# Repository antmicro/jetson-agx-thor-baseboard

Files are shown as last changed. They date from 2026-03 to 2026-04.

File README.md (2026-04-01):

# Antmicro baseboard for Jetson AGX Thor

Copyright (c) 2025-2026 [Antmicro](https://www.antmicro.com)

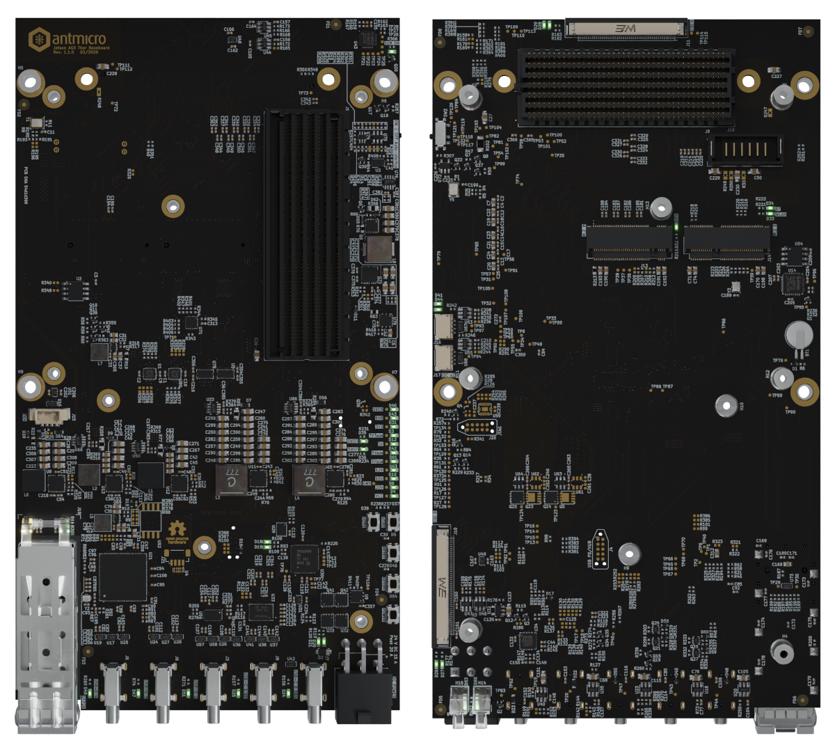
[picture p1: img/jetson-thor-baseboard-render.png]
Jetson Thor Baseboard


## Overview

This repository contains open hardware design files for Antmicro's baseboard for the [NVIDIA Jetson AGX Thor (T5000)](https://www.nvidia.com/en-us/autonomous-machines/embedded-systems/jetson-thor/) System on Module.
The baseboard break-routes common IO-interfaces for standard desktop usage and potential customizations for use in embedded products, [offered as a service](https://offering.antmicro.com/#/hw-process#overview).
The baseboard also features an FMC-style expansion connector, and can be combined with custom-designed accessories in order to accelerate the development of new Thor-based products.
The PCB design files were prepared in KiCad 9.x.

## Key features

* 2 x 50-pin FFC connectors exposing 4 x 4-lane CSI ports from the SoM with independent I2C configuration buses per each CSI port
* SFP port exposing Jetson Thor XFI interface for fiber or copper modules
* M.2 (key-M) for NVMe storage (suggested usage)
* M.2 (key-E) for wireless adapters
* FMC+ expansion connector with PCIe x2, PCIe x1, DisplayPort, CAN, UART, SPI, I2S
* On-board USB 3.2 hub with two downstream-facing ports exposed on USB-C connectors
* Recovery USB-C port for writing Board Support Package (BSP) images to the SoM
* Generic USB-C port which supports video ALT mode and 100 W USB PD sink/source
* Debug USB-C port with debug console and 100 W USB PD sink/source support
* General purpose on-board 8KB EEPROM
* On-board Infineon/SLB9673AU20FW2610XTMA1 TPM
* Two user buttons
* Two user LEDs
* FAN connector
* 100 x 180 mm (3.93 x 7.09 inch) PCB outline

The baseboard has two 50-pin FFC connectors which makes it electrically compatible with a variety of camera modules and video accessories developed by Antmicro. 
These are:

* [GMSL Deserializer Board](https://github.com/antmicro/gmsl-deserializer)
* [SDI-MIPI Video Converter](https://github.com/antmicro/sdi-mipi-video-converter-hw)
* [HDMI to MIPI CSI-2 Bridge](https://github.com/antmicro/hdmi-mipi-bridge)
* [Composite Video to MIPI CSI-2 Bridge](https://github.com/antmicro/cvbs-mipi-bridge)

There is an open hardware CNC-milled [enclosure design](https://github.com/antmicro/jetson-agx-thor-baseboard-enclosure) available for this board. 
In a basic configuration, the Antmicro baseboard for Jetson AGX Thor should be powered with a DC source (24VDC, >130W) through a DC (Molex Mini-Fit) locking connector.

## Project structure

The main directory contains KiCad PCB project files, the LICENSE, and this README, and the img directory contains graphics for this README.

## Licensing

This project is published under the [Apache-2.0](LICENSE) license.

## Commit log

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2025-08-12 [#81778] Add missing schematic sheets
    [SoM.kicad_sch, SoM_ctrl.kicad_sch, SoM_debug.kicad_sch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]
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2025-08-14 [#81970] Fix sheet file name
    [jetson-orin-agx-baseboard.kicad_sch]
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2025-09-10 [#81782] Add PoE
    [#81782] Rename sheets, change ideal diode circuit, add ULS-12/8.3
    [#81782] Remove DC.kicad_sch
    [#81782] change Q3
    [DC.kicad_sch, PoE.kicad_sch, Power.kicad_sch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]
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2025-09-12 [#81970] Fix 12V power rail, add reset and power-up circuitry
    [Power.kicad_sch]
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2025-09-12 [#81970] Add reverse polarity protection, Power sequencing
    [Power.kicad_sch]
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2025-09-12 [#82055] Add USB recovery port
    [#81970] add discharge circuit
    [#81970] Annotation
    [#81782] Annotation and clean up
    [Power.kicad_sch, USB.kicad_sch, USB_debug_dp.kicad_sch]
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2025-09-12 [#82048] Add M.2 key M and key E connectors, route possible connections from the connectors
    [M2.kicad_sch]
2025-09-12 [#82048] Add bus definitions and bus connections from M.2 key M to SoM
    [M2.kicad_sch, SoM_io.kicad_sch, SoM_io2.kicad_sch]
2025-09-12 [#82048] Continue routing bus connections from M.2 key M to SoM
    [SoM_io.kicad_sch, SoM_io2.kicad_sch]
2025-09-12 [#82048] Route PCIe from M.2 key E to SoM
    [M2.kicad_sch, SoM_io.kicad_sch, SoM_io2.kicad_sch]
2025-09-12 [#82048] Route UART, I2S and I2C from M.2 key E to SoM
    [M2.kicad_sch, SoM_io.kicad_sch]
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2025-09-12 [#81970] Create basic connections to the SFP+ connector
    [SFP.kicad_sch]
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2025-09-12 [#81970] Finalize connecting SFP+ to SOM
    [#82054] Update SoM pins definitions
    [#82054] Continue work on I2C
    [#82330] Clean up
    [#81970] Add SFP sheet and power section
    [#82330] Annotation and clean up
    [Peripherals.kicad_sch, Power.kicad_sch, SFP.kicad_sch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]
2025-09-12 [#82330] Add TPM
    [#82330] Add ID-EEPROM
    [#82055] Clean up
    [Peripherals.kicad_sch, USB_debug_dp.kicad_sch]
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2025-09-12 [#81970] Reorganise root schematic and place sheet pins
    [jetson-orin-agx-baseboard.kicad_sch]
2025-09-12 [#81970] Start routing main peripherals on root schematic
    [jetson-orin-agx-baseboard.kicad_sch]
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2025-09-12 [#81970] Route present on root GPIO pins on CSI and Peripherals sheets
    [CSI.kicad_sch, M2.kicad_sch, Peripherals.kicad_sch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]
2025-09-12 [#81970] Route GPIO pins from CSI and peripheral sheets on root schematic
    [jetson-orin-agx-baseboard.kicad_sch]
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2025-09-12 [#82057] Add FMC connector, add grounds for the connector, mark part of the connector overlapping with AGX, add PCIe
    [Expansion_connector.kicad_sch]
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2025-09-12 [#82057] Route UART, SPI, I2S and unused GPIO on SoM and Expansion connector schematics
    [Expansion_connector.kicad_sch, M2.kicad_sch, Peripherals.kicad_sch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]
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2025-09-12 [#82057] Reorganise FMC+ pins so that they obey standard
    [#82057] Add passives to expansion connector
    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
    [Expansion_connector.kicad_sch, Peripherals.kicad_sch, USB_debug_dp.kicad_sch]
2025-09-12 [#82055] Fix debug port power
    [USB_debug_dp.kicad_sch]
2025-09-12 [#82055] Revert back to USB-PD on DP and Debug ports
    [USB.kicad_sch, USB_debug_dp.kicad_sch]
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2025-09-12 [#82055] Add port 3,4 connect to hub
    [#82055] Change I2C bus
    [#82055] Cleanup pin assigment
    [#82055] Cleanup
    [USB.kicad_sch, USB_debug_dp.kicad_sch]
2025-09-12 [#82055] Fix labels
    [USB.kicad_sch, USB_debug_dp.kicad_sch]
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2025-09-12 [#82757] Cleanup: reorganise page numbers and fix annotations
    [CSI.kicad_sch, Expansion_connector.kicad_sch, M2.kicad_sch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]
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2025-09-12 [#82837] Fix USB Hub configuration section
    [usb_hub.kicad_sch]
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2025-09-12 [#82837] Fix USB recovery and flashing section
    [jetson-agx-thor-baseboard.kicad_sch, recovery_usb.kicad_sch, som_power.kicad_sch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]
2025-09-12 [#82837] Start fixing USB DP Alt mode sheet: clean up, define DP bus, rename USB nets and buses to match rest of the schematic
    [som_io2.kicad_sch, usb_dp.kicad_sch]
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2025-09-12 [#82837] Add JTAG debug section to SoM_IO sheet. Delete SoM_Debug sheet and rearrange schematic pages
    [jetson-agx-thor-baseboard.kicad_sch, power.kicad_sch, som_debug.kicad_sch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]
2025-09-12 [#82847] Add missing three LEDs on mock-up
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2025-09-12 [#82837] Map interfaces from AGX to Thor on SoM schematic and add level shifters for 1V8 interfaces
    [som_io.kicad_sch, som_io2.kicad_sch]
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2025-09-12 [#82837] Finish mapping interfaces, waiting for new SoM symbol
    [#82837] Add GPIO level shifter and route USB related GPIO on root
    schematic
    [#82837] WIP: Modify Power-up and reset section
    [expansion_connector.kicad_sch, jetson-agx-thor-baseboard.kicad_sch, m2.kicad_sch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]
2025-09-12 [#82837] Finish Power-up and reset section
    [#82837] Add 1V8 buck converter and wire power seqencer programmer
    [#82837] WIP: Add 18V DC-DC converter
    [#82837] Ditch idea of 18V DC-DC converter, for seqencing just use power mosfets to supply High voltage to SOM, modify VCC line for higher voltage
    [power.kicad_sch, som_power.kicad_sch, usb_debug_pd.kicad_sch]
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2025-09-12 [#82837] Swap SoM form AGX Orin to Thor with all of its connections
    [m2.kicad_sch, som_io.kicad_sch, som_io2.kicad_sch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]
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2025-09-12 [#82837] Fix voltage levels on power sequencer, assign leftover GPIO pins to expansion connector
    [expansion_connector.kicad_sch, jetson-agx-thor-baseboard.kicad_sch, m2.kicad_sch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]
2025-09-12 [#82837] Finish mapping PCIe and SFP+ connections on SoM
    [#82837] WIP: correct ERC errors
    [#82837] WIP: correct ERC errors, fix signal direction of most buses
    [#82837] Fix all ERC errors
    [csi.kicad_sch, expansion_connector.kicad_sch, jetson-agx-thor-baseboard.kicad_sch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]
2025-09-12 [#83224] Import all of the components to PCB and divide them into functional groups
    [m2.kicad_sch, recovery_usb.kicad_sch]
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2025-09-12 [#83224] Swap USB port 3 and 4 on hub to get less crossed lines
    [usb_hub.kicad_sch]
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2025-09-12 [#83224] Place power-up and reset section
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2025-10-06 [#83396] Define Net Classes for all interfaces
    [#83396] Define Net Classes for all interfaces
    [csi.kicad_sch, expansion_connector.kicad_sch, m2.kicad_sch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]
2025-10-06 [#83396] Route high speed signals to inner layers
    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
    [usb_dp.kicad_sch]
2025-10-06 [#83396] Route M.2 key M PCIe
    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
    [m2.kicad_sch]
2025-10-06 [#83396] Route M.2 key E PCIe
    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
    [m2.kicad_sch]
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2025-10-06 [#83396] WIP: Route USB DP Alt mode - VBUS Problem
    [usb_dp.kicad_sch]
2025-10-06 [#83396] Change SI7613DN-T1-GE3 to SISS05DN-T1-GE3 transistor on power section and remove soft start
    [power.kicad_sch]
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2025-10-06 [#83396] WIP: Route PCIe on expansion connector, change Expansion connector pinout to ease out routing PCIe
    [expansion_connector.kicad_sch]
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2025-10-06 [#83396] Route USB connector high speed signals and start routing USB connector power
    [usb_debug_pd.kicad_sch, usb_hub.kicad_sch]
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2025-10-06 [#83396] Update all symbols from library and clear all ERC errors
    [csi.kicad_sch, expansion_connector.kicad_sch, jetson-agx-thor-baseboard.kicad_sch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]
2025-10-06 [#83396] Implement small post review fixes eg. correct LED resistor values, update sheet table, delete four wire connections
    [csi.kicad_sch, expansion_connector.kicad_sch, level_shifter_x8.kicad_sch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]
2025-10-06 [#83396] Continue post review fixes according power and M.2
    [expansion_connector.kicad_sch, jetson-agx-thor-baseboard.kicad_sch, m2.kicad_sch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]
2025-10-06 [#83396] Continue post review fixes according USB Hub
    [expansion_connector.kicad_sch, som_io.kicad_sch, usb_debug_pd.kicad_sch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]
2025-10-06 [#83396] Continue post review fixes according USB Hub flash
    [jetson-agx-thor-baseboard.kicad_sch, usb_hub.kicad_sch]
2025-10-06 [#84355] Prepare power section for deletion of power sequencer: reorganize power indicator LEDs, add SoM Medium Voltage power switch, add power monitrs and write down sequencing table
    [power.kicad_sch]
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2025-10-06 [#84355] Clear ERC problems
    [peripherals.kicad_sch, power.kicad_sch, som_power.kicad_sch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]
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2025-10-10 [#83607] Sch: Rework power
    [power.kicad_sch, usb_debug_pd.kicad_sch, usb_dp.kicad_sch]
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2025-10-16 [#85326] Correct USB/DP polarity
    [usb_dp.kicad_sch]
2025-10-16 [#85326] Fix annotation, set USBPD ideal diodes to DNP, add DC-DC rule zones
    [csi.kicad_sch, dcdc.kicad_sch, expansion_connector.kicad_sch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]
2025-10-16 [#85326] Fix malformed DNP components
    [csi.kicad_sch, dcdc.kicad_sch, expansion_connector.kicad_sch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]
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2025-10-17 [#85326] Fix USB-C 2 ID and enable handling
    [csi.kicad_sch, dcdc.kicad_sch, expansion_connector.kicad_sch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]
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2025-10-21 [#85326] Fix USB-C DP alt mode
    [usb_dp.kicad_sch]
2025-10-21 [#85326] M.2 Key E fixes
    [m2.kicad_sch, som_io.kicad_sch]
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2025-10-21 [#85326] Fix Thor symbol, Free reserved GPIOs
    [jetson-agx-thor-baseboard.kicad_sch, peripherals.kicad_sch, som_io.kicad_sch]
2025-10-21 [#85326] Fix incorrect GPIO voltage levels, add SFP related TVS
    [csi.kicad_sch, sfp.kicad_sch, som_io.kicad_sch]
2025-10-21 [#85326] Fix FAN signals, add testpoints, add DP capaciors, fix optional JTAG connector
    [som_io.kicad_sch, som_io2.kicad_sch]
2025-10-21 [#85326] Change SoM IO level shifters for ones with pull-ups. add pull-ups to I2C lines
    [level_shifter_x8.kicad_sch, som_io.kicad_sch]
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2025-10-21 [#85488] Correct Power sequence
    [dcdc.kicad_sch, power.kicad_sch, som_power.kicad_sch]
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2025-10-21 [#85488] Sch: Fix resistor values
    [som_power.kicad_sch]
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2025-10-21 [#85488] Apply power sequencing circuit fixes
    [dcdc.kicad_sch, som_power.kicad_sch]
2025-10-21 [#85326] Update level shifters, fix UART cross
    [level_shifter_x8.kicad_sch, m2.kicad_sch, som_io.kicad_sch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]
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2025-10-22 [#85326] Change SFP+ to SFP28; minor corrections to sch
    [csi.kicad_sch, dcdc.kicad_sch, expansion_connector.kicad_sch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]
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2025-10-28 BoM fix
    [dcdc.kicad_sch, peripherals.kicad_sch, power.kicad_sch]
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2025-10-31 [#86267] Fix trace impedance
2025-11-03 [#86267] Review fixes
    [som_power.kicad_sch]
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2025-11-04 [#85702] Reordered FMC connector blocks to be consistant with table in the standard
    [expansion_connector.kicad_sch]
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2026-02-19 [#88834] SPF connector symbol and footprint change
    Due to symbol U773GC16382071 division into separate connector
    UE763GA202600T and case U773GC16382071 in issue [#88716], correction is
    done in this projects schematic and footprint
    [sfp.kicad_sch]
2026-02-19 [#88834] Reference symbol cleanup
    Edge connector reference symbol correction from J21 to J12
    [sfp.kicad_sch]
2026-02-19 [#88665] Changed component R228 R362 R361 R356
    Component changed to standalone resistors
    [som_io.kicad_sch]
2026-02-19 [#88665] All Resistors array replaced by standalone resistors
    Task done as described in #88665
    [csi.kicad_sch, peripherals.kicad_sch, sfp.kicad_sch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]
2026-02-19 [#88665] SFP connector footprint position fix, UMPT-06-06.5-G-V-S-W-TR symbol updated from library
    1. SFP connector position fix due to footprint modification in library
    2. Component UMPT-06-06.5-G-V-S-W-TR updated from library after fix
    [expansion_connector.kicad_sch]
2026-02-19 [#88664] DF2S30FS diodes replaced by ESDA25P35-1U1M
    DF2S30FS -> ESDA25P35-1U1M, changes done on schematics and PCB editor
    [dcdc.kicad_sch, usb_debug_pd.kicad_sch, usb_dp.kicad_sch]
2026-02-19 [#88664] ESD9X5.0ST5G diodes replaced by PESD5Z5_0F, added TVS on Fan 12V
    ESD9X5.0ST5G -> PESD5Z5_0F, changes done on schematics and PCB editor,
    added TVS for fan 12V
    [dcdc.kicad_sch, peripherals.kicad_sch, power.kicad_sch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]
2026-02-19 [#88834] SPF connector symbol and footprint change
    Due to symbols UE763GA202600T and U773GC16382071 center position
    correction, symbols position shift on project
2026-02-19 Fix via assigned as SH for SFP cage, change to GND
2026-02-19 [#88671] Fix 5VAON_EN resistor divider
    Changed R251 value from 499k to 2k2 that results DC/DC converter (U75)
    starts when Vcc >= 23.48V.
    Added C6 capasitor as described in User's manual (100n 50V)
    [dcdc.kicad_sch]
2026-02-19 [#88671] Fix 5VAON_EN resistor divider after review
    Changed R251 value from 2k2 to 2k37 that results DC/DC converter (U75)
    starts when Vcc >= 22.05V in best scenario, 22.48V in worst case
    scenario.
    [dcdc.kicad_sch]
2026-03-19 [#88668] VIN_PWR_ON line fix
    Removed Removed R45, Removed R44,Removed Q30
    [dcdc.kicad_sch, som_power.kicad_sch]
2026-03-19 [#88668] CARRIER_PWR_ON pull-up fix
    [dcdc.kicad_sch]
2026-03-19 Fix R251 symbol on schematic, improve readability of U75 EN voltage divider
    [dcdc.kicad_sch]
2026-03-19 [#88668] Fix Q30 functionality on schematic
    When MODULE_POWER_ON signal drops, added delay using LTC6994:
    - Delay time set according to Figure 5-3 in Jetson Thor Series Modules
    Design Guide to more than 10[ms]
    - Delay time is controlled by R408, when value is 124k (normal
    scenario), delay is 10.158[ms], in worst case scenario delay is
    10.057[ms]
    - Delay set only for falling edge
    TODO: symbol needs to be corrected in library
    [som_power.kicad_sch]
2026-03-19 [#89204] Schema signal SOM_POWER_BTN fix and PCB update
    Schema fix: SOM_POWER_BTN disconected from FORCE_SHDN
    PCB updated with Q30 modification and schema fix from this commit
    [som_power.kicad_sch]
2026-03-19 [#89204] Symbol LTC6994CDCB-1#TRMPBF updated from library
    After library changes in [#89200] symbol and it's footprint
    LTC6994CDCB-1#TRMPBF was updated on schema and PCB
    [som_power.kicad_sch]
2026-03-19 Fix +20V converter now is power up from Vcc not Vcc_in
    After this change +20V DC/DC converter is safe from reverse voltage
    connected to board
    [dcdc.kicad_sch]
2026-03-19 [#89204] Power selector with MAX16013
    Added over-voltage protection using MAX16013 IC, also reverse-voltage
    protection was redesigned using the same IC MAX16013 as in OVP
    [power.kicad_sch]
2026-03-19 [#89204] Correction of VCC plane on layer 1 and 4
    After modifications of power selector planes required
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2026-03-19 [#89728] Replace 6.5mm studs with 10mm ones
    [jetson-agx-thor-baseboard.kicad_sch]
2026-03-19 [#89536] Replace lightpipes with 1271.1001 model, place them in correct positions on PCB
    [recovery_usb.kicad_sch, usb_debug_pd.kicad_sch, usb_dp.kicad_sch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]
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2026-03-19 [#89536] Replace expansion connectors to achieve 10mm mating height
    Used:
    ASP-208571-01 (mating: ASP-184329-01 )
    UMPT-06-02.5-L-V-S-W-TR (mating: UMPS-06-07.5-L-V-S-W-TR)
    [expansion_connector.kicad_sch]
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2026-03-19 [#89645] Replace SYS_VIN_SV LDO with LD39100PUR
    [power.kicad_sch]
2026-03-19 [#89645] Add lightpipe for boot and power LED under the power connector
    [power.kicad_sch, som_power.kicad_sch]
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2026-03-19 [#89536] Fix U79 feedback
    [power.kicad_sch]
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2026-03-19 [#90855] Replace SIC431AED-T1-GE3 dc-dc ICs with SIC437AED-T1-GE3
    [dcdc.kicad_sch]
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2026-03-19 [#90793] Change R311 to 100k, replace L8 to Bourns SRP7028A-3R3M, re-route 5V_AON DC-DC area, change power monitors I2C addresses 0x40 > 0x45 and 0x44 > 0x46
    [dcdc.kicad_sch]
2026-03-19 [#90760] Apply fixes after review
    [dcdc.kicad_sch, som_power.kicad_sch, usb_debug_pd.kicad_sch]
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2026-03-19 [#90793] Correct symbol and footprint properties, sync sch to PCB, change J21 to top entry connector
    [peripherals.kicad_sch, power.kicad_sch, recovery_usb.kicad_sch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]
2026-03-19 [#90793] Update project date, fix U79 layout, add schematic note regarding U9
    [power.kicad_sch, som_power.kicad_sch]
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2026-03-19 [#90793] Correct A3 position, clean ERC and DRC
    [expansion_connector.kicad_sch, peripherals.kicad_sch, som_power.kicad_sch]
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2026-05-18 [#96452] Fix power supply link and DisplayPort description
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2026-06-15 [#97638] Fix J4 wireframe descriptor position
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2026-06-23 [#99331] Fix: Swap ID EEPROM I2C signals
2026-06-23 [#99331] Fix: Correct U30 I2C addresses
2026-06-23 [#99331] Fix: Correct D24 status LED control
2026-06-23 [#99331] Change resistor values to shorten DNP
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
